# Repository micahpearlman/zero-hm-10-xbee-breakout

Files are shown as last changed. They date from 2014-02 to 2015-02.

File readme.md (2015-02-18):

## Overview ##

This is an 3.3V XBee breakout of the HM-10 Bluetooth Low Energy Module.

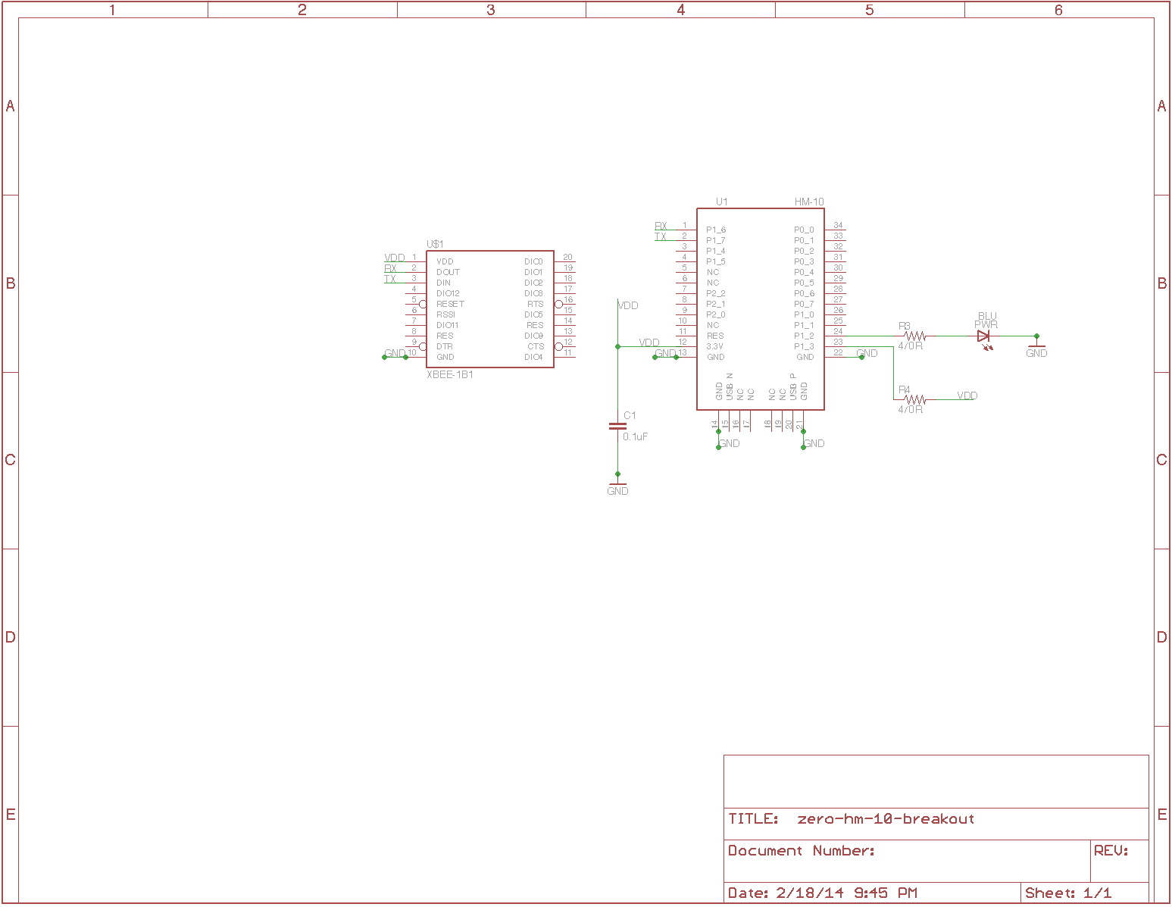
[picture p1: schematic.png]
what Schematic

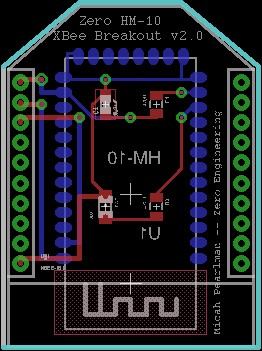
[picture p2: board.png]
Board


## License ##

Creative Commons Share and Share Alike

## Parts ##

[Order a complete board on Tindie](https://www.tindie.com/products/micahpearlman/zero-xbee-ble/)

[Parts List](https://raw2.github.com/micahpearlman/zero-hm-10-xbee-breakout/master/parts-list.txt)

[Order PCB from Osh Park](https://oshpark.com/shared_projects/l8zO7AMg)

## References ##

[Data Sheet](https://github.com/micahpearlman/zero-hm-10-xbee-breakout/blob/master/docs/hm-10-datasheet.pdf)

HM-10 purchase: http://www.fasttech.com/product/1292002-ti-cc2540-bluetooth-4-0-ble-2540-transparent

Great article: http://letsmakerobots.com/node/38009

## Open HW Reference Designs:

https://github.com/Ladvien/HM-10

https://github.com/SamEA/Bluetooth_Low_Energy

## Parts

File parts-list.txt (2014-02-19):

Partlist

Exported from zero-hm-10-breakout.sch at 2/19/14 10:23 AM

EAGLE Version 6.5.0 Copyright (c) 1988-2013 CadSoft

Assembly variant: 

Part     Value          Device                    Package      Library             Sheet

C1       0.1uF          0.1UF-25V(+80/-20%)(0603) 0603-CAP     SparkFun-Capacitors 1
PWR      BLU            LEDCHIPLED_0805           CHIPLED_0805 adafruit            1
R3       470R           0.3OHM-1/8W-1%(0805)      0805         SparkFun-Resistors  1
R4       470R           0.3OHM-1/8W-1%(0805)      0805         SparkFun-Resistors  1
U$1      XBEE-1B1       XBEE-1B1                  XBEE-1       SparkFun-RF         1
U1       HM-10          HM-10                     HM-10        HM-10_BLE           1

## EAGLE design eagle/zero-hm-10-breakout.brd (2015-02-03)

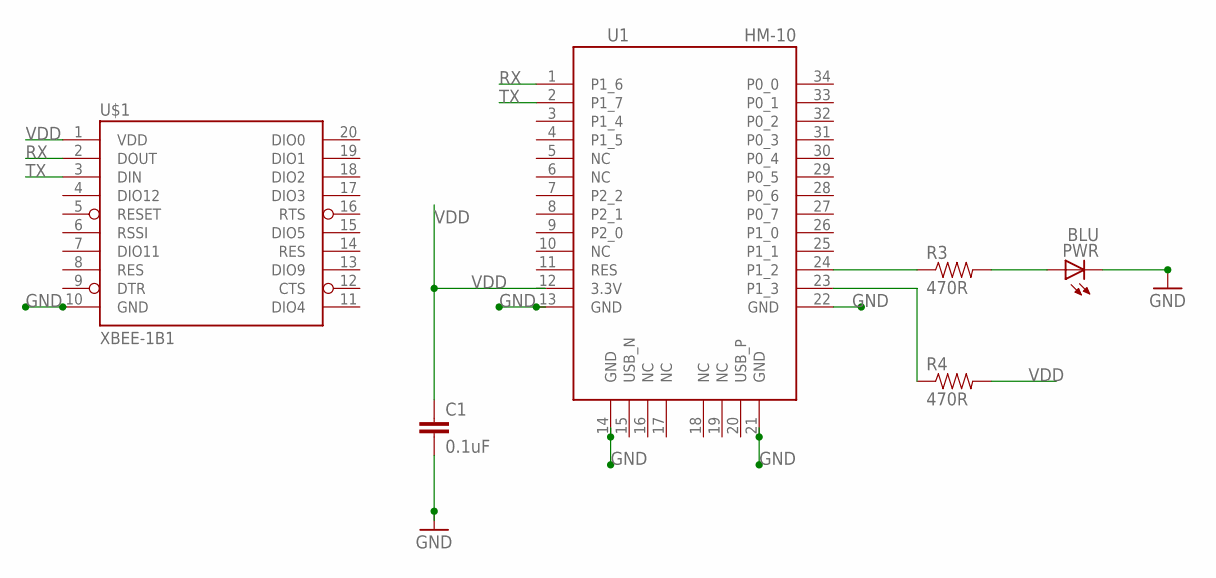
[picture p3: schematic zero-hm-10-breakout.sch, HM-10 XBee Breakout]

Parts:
C1: 0.1uF; 0603-CAP
PWR: BLU; CHIPLED_0805
R3, R4: 470R; 0805
U1: HM-10
U$1: XBEE-1B1; XBEE-1

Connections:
GND: C1.2, PWR.C, U1.13 (GND), U1.14 (GND), U1.21 (GND), U1.22 (GND), U$1.10 (GND)
unnamed: PWR.A, R3.2
unnamed: R3.1, U1.24 (P1_2)
unnamed: R4.1, U1.23 (P1_3)
RX: U1.1 (P1_6), U$1.2 (DOUT)
TX: U1.2 (P1_7), U$1.3 (DIN)
VDD: C1.1, R4.2, U1.12 (3.3V), U$1.1 (VDD)

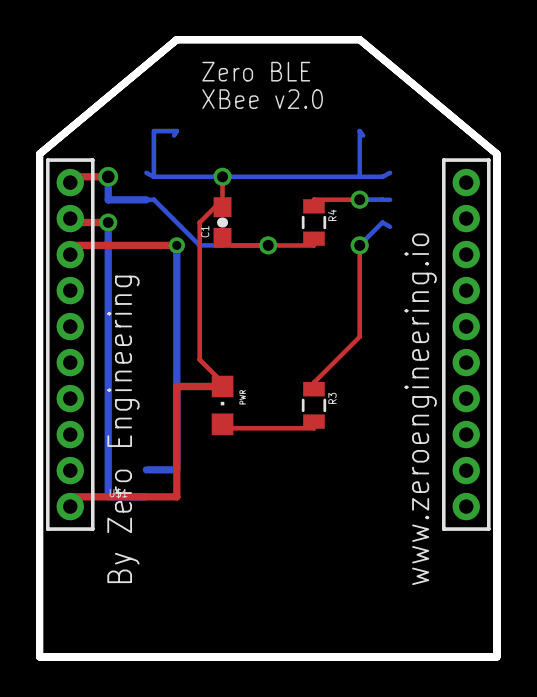
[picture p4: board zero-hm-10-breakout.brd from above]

Board: 2 copper layers, 25.4 x 34.3 mm, 6 parts (1 on the bottom side), 7 nets.

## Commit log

2014-02-02 just about todo routing
    [zero-hm-10-breakout.brd, zero-hm-10-breakout.sch]
2014-02-02 first working routing
    [zero-hm-10-breakout.brd, zero-hm-10-breakout.sch]
2014-02-02 good layout
    [zero-hm-10-breakout.brd]
2014-02-02 better board layout
    [zero-hm-10-breakout.brd]
2014-02-02 add text to silk screen
    [zero-hm-10-breakout.brd]
2014-02-02 couple more minor tweaks to text
    [zero-hm-10-breakout.brd]
2014-02-02 final sent to oshpark. tag it and bag it.
    [zero-hm-10-breakout.brd]
2014-02-03 added missing capacitor
    [zero-hm-10-breakout.brd, zero-hm-10-breakout.sch]
2014-02-03 added schematic image
2014-02-19 Fixed RX/TX being backwards and removed the RX/TX LEDs
    [zero-hm-10-breakout.brd, zero-hm-10-breakout.sch]
2014-02-19 updated board and schematic images and parts list
    [zero-hm-10-breakout.brd]
2015-02-03 updated silkscreen
    [zero-hm-10-breakout.brd]
2015-02-15 removed old
    [BLE Development Board v2.2.brd, BLE Development Board v2.2.sch, BLEbee-1_0_0-REV-B.brd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]
2015-02-15 cleaned up directories
    [zero-hm-10-breakout.brd, zero-hm-10-breakout.sch]

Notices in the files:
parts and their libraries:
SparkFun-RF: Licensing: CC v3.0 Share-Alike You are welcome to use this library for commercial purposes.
